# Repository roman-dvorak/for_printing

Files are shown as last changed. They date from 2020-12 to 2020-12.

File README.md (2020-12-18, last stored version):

# TFRPM01B sensor
Revolutions per minute meter for UAV.
It is designed to direct connection to Pixhawk controller (CUAV V5+) trough standard I²C connector. The device [is supported by PX4 firmware](https://docs.px4.io/master/en/sensor/thunderfly_tachometer.html).
At the input of meter is supposed a pulse signal from optical encoder, hall sensor etc.
The hardware is inteded to be used for helicopter and autogyro rotor RPM measurement, but its counting capability is up to 20 kHz therefore it should be used for propeller or engine RPM measurement.

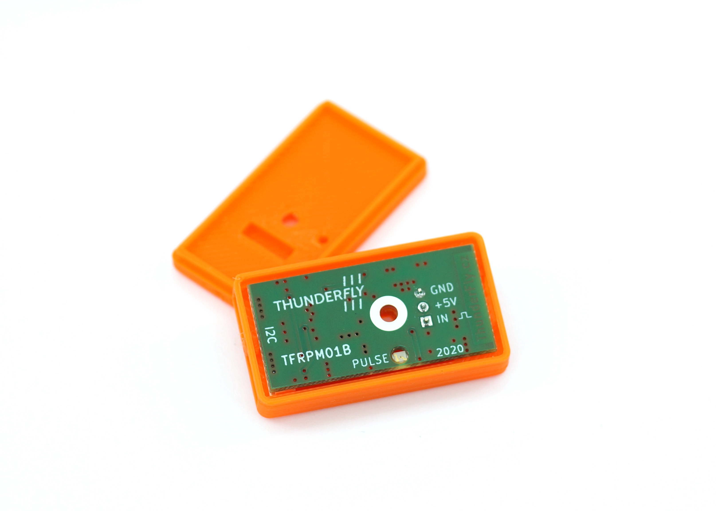
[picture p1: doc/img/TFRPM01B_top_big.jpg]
Top view on I2C RPM sensor


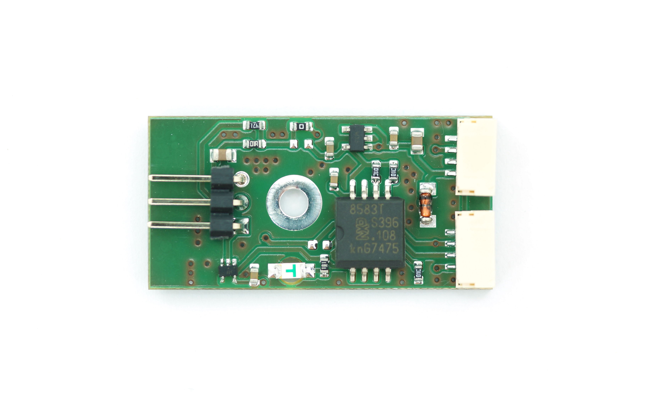
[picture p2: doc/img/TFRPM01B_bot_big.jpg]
Bottom view on I2C RPM sensor


The 3Pin probe connector is powered from I²C bus trough RC filter which limits current and voltage spikes to sensor probe.
Therefore sensor is resistant to short circuit at the probe connector power.

The two I²C Pixhawk connectors are connected to each other. This feature allows easily nesting with other I²C devices to single Pixhawks I²C port.

### Sensor options

The sensor could be used with multiple sensor probes. The most used one is a hall effect probe.

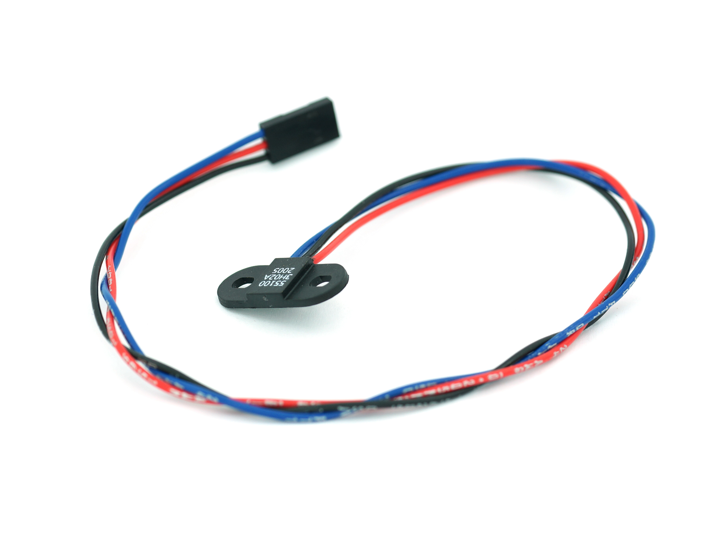
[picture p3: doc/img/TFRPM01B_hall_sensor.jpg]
TFRPM01B hall effect magnetic sensor


The probe should be connected to the sensor board as follows

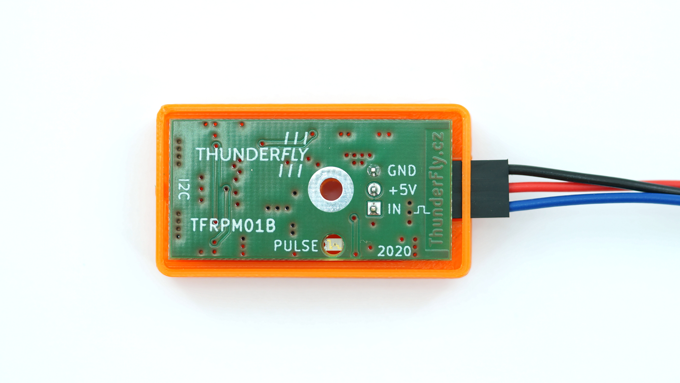
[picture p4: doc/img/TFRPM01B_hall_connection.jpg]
TFRPM01B hall effect magnetic sensor connection


Correct connection of the probe could be check by magnet, the PULSE LED switch on and off according to magnet presence. The sensor board needs to be powered from at least one I²C port during the test.

The sensor could also be used with other probe types. The one example is [TFPROBE01](https://github.com/ThunderFly-aerospace/TFPROBE01), which combines the optical reflective sensor and magnetic hall-effect sensor in one device. However the TFRPM01 sensor needs matching the input parameters to certain probe types. The default configuration is reflected in the following schematics.

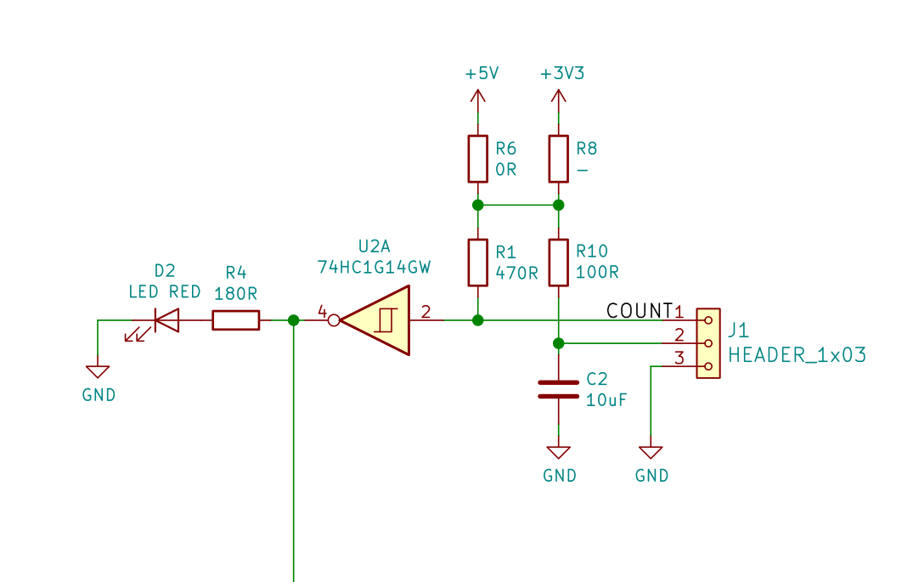
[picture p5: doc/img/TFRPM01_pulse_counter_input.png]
TFRPM01B probe input circuit


As can be seen from the schematics the default probe power selection is +5V, protected by resistor R10 to about 50 mA short-circuit current. The pull-up resistor R1 with default value 470 Ohm is quite hard and it is generally unsuitable to most optical probes with open-collector outputs. Therefore the resistor R1 should be interchanged to the more suitable value (That could be requested during the order process).

## Parameters

  * Pulse frequency range  0-20kHz (maximum RPM value varies by pulse number per revolution)
  * Operating and storage temperature range -20 °C  to +40 °C (limited by case material)
  * Operating input voltage range 3.6-5 V
  * Short circuit protection on probe connector.

## Where to get it?

ThunderFly RPM counter is commercially available from [ThunderFly s.r.o.](https://www.thunderfly.cz/), write an email to info@thunderfly.cz or shop at [Tindie store](https://www.tindie.com/products/thunderfly/tfrpm01-drone-rpm-tachometer-sensor/).

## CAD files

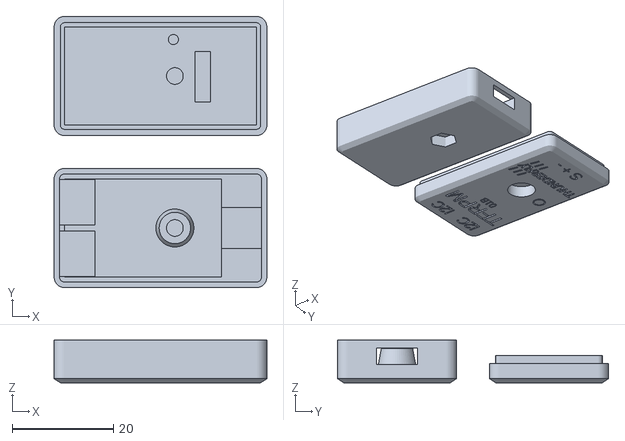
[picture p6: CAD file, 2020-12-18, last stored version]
hw/CAD/stl/RPM_case.stl
42.0 x 53.5 x 8.40

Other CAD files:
hw/CAD/parameters.scad
hw/CAD/src/RPM_case.scad
hw/CAD/src/TFlogo.scad

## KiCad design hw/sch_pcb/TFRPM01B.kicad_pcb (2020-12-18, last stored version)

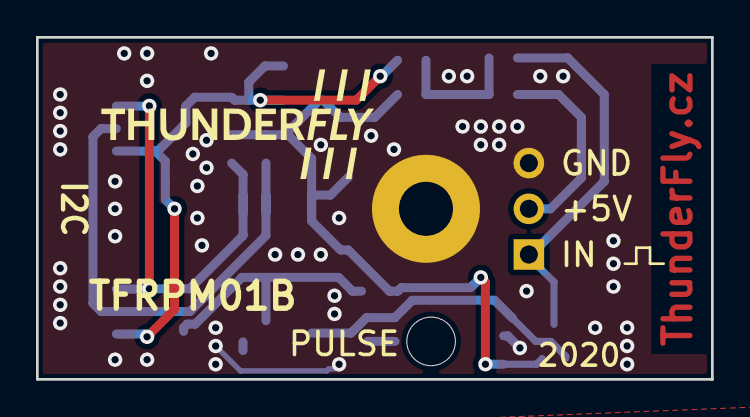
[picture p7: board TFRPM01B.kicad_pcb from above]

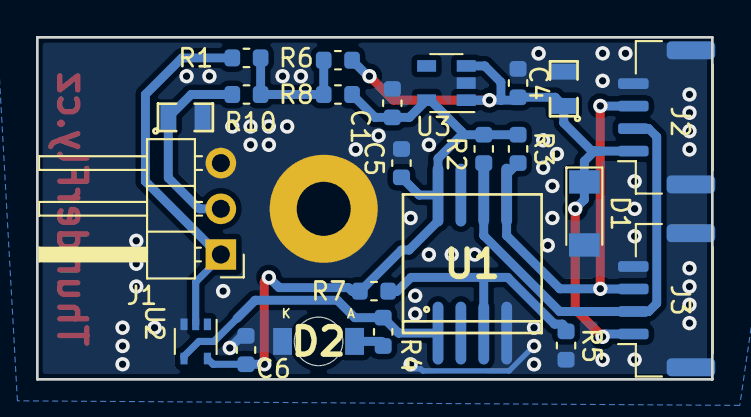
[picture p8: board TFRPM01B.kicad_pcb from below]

Board: 2 copper layers, 37.5 x 19.0 mm, 24 parts (24 on the bottom side), 11 nets.

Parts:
C1: 1uF; SMD-0603
C2, C3: 10uF; SMD-0805
C4, C5, C6: 100nF; SMD-0603
D1: ZENER-5.6V; Diode-MiniMELF_Standard
D2: LED RED; LED_1206
J1: HEADER_1x03; PinHeader_1x03_P2.54mm_Horizontal
J2, J3: SM04B-GHS-TB; JST_GH_SM04B-GHS-TB_1x04-1MP_P1.25mm_Horizontal
M2: M3; MountingHole_3mm
R1: 470R; SMD-0603
R2, R3, R5: 10k; SMD-0603
R4: 180R; SMD-0603
R6: 0R; SMD-0603
R7, R8: -; SMD-0603
R10: 100R; SMD-0603
U1: PCF8583; SOT176-1
U2: 74AHC1G14GV; SOT-353_SC-70-5
U3: MIC5504-3.3YM5; SOT-23-5

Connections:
+3V3: C1.1, C5.1, C6.1, R2.1, R3.1, R7.1, R8.1, U1.8, U2.5, U3.5
+5V: C3.1, C4.1, D1.1, J2.1, J3.1, R6.1, U3.1, U3.3
/COUNT: J1.1, R1.2, U2.2
/SCL: J2.2, J3.2, R2.2, U1.6
/SDA: J2.3, J3.3, R3.2, U1.5
GND: C1.2, C2.2, C3.2, C4.2, C5.2, C6.2, D1.2, D2.1, J1.3, J2.4, J2.MP, J3.4, J3.MP, M2.1, R5.2, U1.4, U2.3, U3.2
unnamed: C2.1, J1.2, R10.1
unnamed: D2.2, R4.2
unnamed: R1.1, R6.2, R8.2, R10.2
unnamed: R4.1, U1.1, U2.4
unnamed: R5.1, R7.2, U1.3

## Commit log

2020-12-18 Update from https://github.com/roman-dvorak/TFRPM01/commit/3a6d0bbd137cea8deb38b12fe1c789ad3b90cbbc
    [RPM_case.scad, RPM_case.stl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]
2020-12-18 Update from https://github.com/roman-dvorak/TFRPM01/commit/22aee5a2d985597d7f760180577d276562867e3e
    [RPM_case.scad, RPM_case.stl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]
